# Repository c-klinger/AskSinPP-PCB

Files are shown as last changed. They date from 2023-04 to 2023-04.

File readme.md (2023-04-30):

# AskSin++ PSB
Collection of my PCBs for building Homebrew devices using [AskSin++](https://github.com/pa-pa/AskSinPP).

## HB-UNI-328P
soon...

## HB-UNI-328P-SMALL
Flexible and small (49x49mm) PCB for AskSin++ devices with multiple power options. Small enough to fit into devices that integrate into german wall socket / switch series.

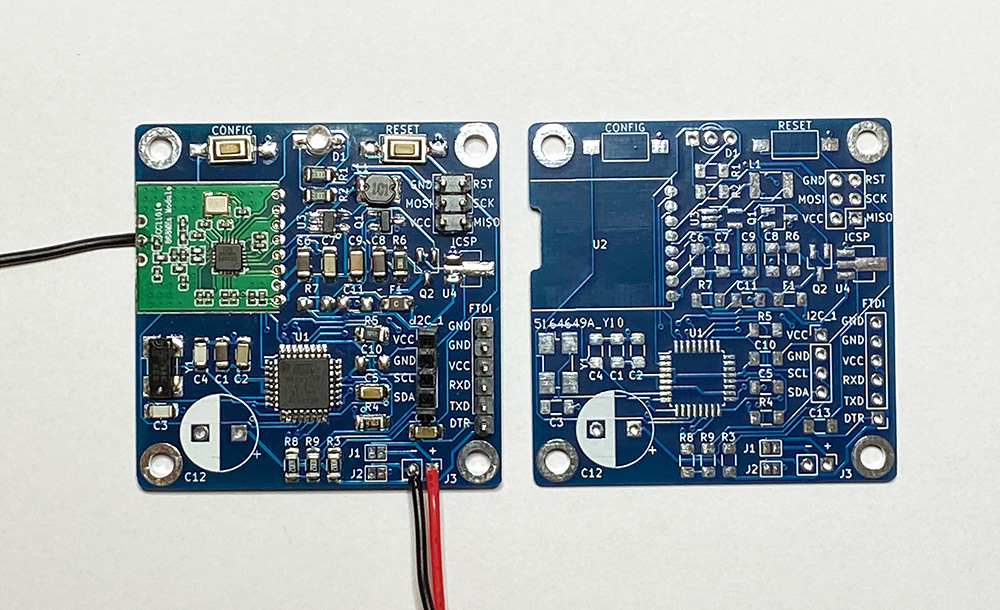
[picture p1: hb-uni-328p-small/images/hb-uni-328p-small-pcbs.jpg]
PCB Picture


[Schematics](https://github.com/c-klinger/AskSinPP-PCB/blob/main/hb-uni-328p-small/hb-uni-328p-small.pdf)

### Bill of Material

| Pos | References | Description | Value | Size | Quantity | Order Links \* | Notes |
|-----|---|---|---|---|---|---|---|
| 01 | U1 | ATmega328P(B) |  | TQFP-32 | 1 | [Reichelt](https://www.reichelt.de/8-bit-atmega-avr-mikrocontroller-32-kb-20-mhz-tqfp-32-atmega-328pb-au-p269093.html), [Aliexpress](https://s.click.aliexpress.com/e/_DmFgvzj) | |
| 02 | U2 | CC1101 Module |  |  | 1 | [Aliexpress](https://s.click.aliexpress.com/e/_DnFmipB) | |
| 03 | U3 | MAX1724EZK33 | | SOT-23 | 1 | [Mouser](https://www.mouser.de/ProductDetail/Analog-Devices-Maxim-Integrated/MAX1724EZK33%2bT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),  [Aliexpress](https://s.click.aliexpress.com/e/_DEjlEQt) | Only for Poweroption 1
| 04 | U4 | HT7533 | | SOT-89 | 1 | [ELV](https://de.elv.com/spannungsregler-33v-ht-7533-1-smd-sot-89-056535),  [Aliexpress](https://s.click.aliexpress.com/e/_Dkyk1p7)  | Only for Poweroption 2
| 05 | Q1 | IRLML6244 | | SOT-23 | 1 | [Reichelt](https://www.reichelt.de/mosfet-n-kanal-20-v-6-3-a-rds-on-0-021-ohm-sot-23-irlml-6244-p132145.html), [Aliexpress](https://s.click.aliexpress.com/e/_DmmdQxj) | only for Poweroption 1 
| 06 | Q2 | IRLML5203 | | SOT-23 | 1 | [Reichelt](https://www.reichelt.de/mosfet-p-kanal-30-v-3-a-rds-on-0-098-ohm-sot-23-irlml-5203-p108740.html), [Aliexpress](https://s.click.aliexpress.com/e/_DmmdQxj) | only for Poweroption 2 
| 07 | C1, C6, C8, C10, C11 | Capacitor | 10uF | 1206 | 4 (max) | [Reichelt](https://www.reichelt.de/ch/de/vielschicht-kerko-10-f-16v-125-c-kem-x7r1206-10u-p207163.html),  [Aliexpress](https://s.click.aliexpress.com/e/_DCrWg7b) | C8 for Poweroption 1, C10 + C11 for Poweroption 2
| 08 | C2, C7, C5 | Capacitor | 100nF | 1206 | 3 | [Reichelt](https://www.reichelt.de/smd-vielschicht-keramikkondensator-100n-10--x7r-g1206-100n-p22889.html),  [Aliexpress](https://s.click.aliexpress.com/e/_DCrWg7b) | |
| 09 | C3, C4 | Capacitor | 9-12pF | 1206 | 2 | [Reichelt](https://www.reichelt.de/vielschicht-kerko-1206-10-pf-5-cog-50-v-125-c-ve-4k-npo-g1206-10p-p31885.html), [Aliexpress](https://s.click.aliexpress.com/e/_DCrWg7b) | |
| 10 | C9  | Capacitor | 33nF | 1206 | 1 | [Reichelt](https://www.reichelt.de/smd-vielschicht-keramikkondensator-33n-10--x7r-g1206-33n-p22890.html), [Aliexpress](https://s.click.aliexpress.com/e/_DCrWg7b) | only for Poweroption 1 |
| 11 | C12  | Electrolytic Capacitor | 1000uF |  | 1 | [Reichelt](https://www.reichelt.de/elko-1000-f-50v-105-c-rad-lxz-50-1k0-p166432.html), [Aliexpress](https://s.click.aliexpress.com/e/_DCrWg7b) | only for Poweroption 2 |
| 12 | C13  | Capacitor | 10nF | 1206 | 1 | [Reichelt](https://www.reichelt.de/vielschicht-kerko-1206-10-nf-10-x7r-50-v-125-c-x7r-g1206-10n-p31897.html), [Aliexpress](https://s.click.aliexpress.com/e/_DCrWg7b) |  | 
| 13 | D1 | Dual LED | | 3mm | 1 | [Reichelt](https://www.reichelt.de/ch/de/led-3-mm-tht-3-pin-rot-gruen-627-565-nm-40-40-mcd-60--kbt-l-115wegw-p231039.html), [Aliexpress](https://s.click.aliexpress.com/e/_DFd0iCd) |  |
| 14 | F1 | Fuse (PTC) | 6V, 250mA | 1206 | 1 | [Aliexpress](https://s.click.aliexpress.com/e/_DEQvumh) | for Poweroption 1 |
| | F1 | Fuse (PTC) | 16V, 250mA | 1206 | 1 | [Reichelt](https://www.reichelt.de/ptc-sicherung-smd-1206-16v-350ma-rueckstellend-ptc-fsmd0351206--p279338.html), [Aliexpress](https://s.click.aliexpress.com/e/_DEQvumh) | for Poweroption 2 |
| 15 | J3 | Pin Header 2.54mm |  | 2x1 | 1 | [Reichelt](https://www.reichelt.de/ch/de/stiftleisten-2-54-mm-1x02-gerade-mpe-087-1-002-p119879.html), [Aliexpress](https://s.click.aliexpress.com/e/_Dl2TPCt) | optional |
| 16 | J4 | Pin Header 2.54mm |  | 6x1 | 1 | [Reichelt](https://www.reichelt.de/ch/de/stiftleisten-2-54-mm-1x06-gerade-mpe-087-1-006-p119883.html), [Aliexpress](https://s.click.aliexpress.com/e/_Dl2TPCt) | optional |
| 17 | J5 | Pin Header 2.54mm |  | 3x2 | 1 | [Reichelt](https://www.reichelt.de/ch/de/stiftleisten-2-54-mm-2x03-gerade-mpe-087-2-006-p119893.html), [Aliexpress](https://s.click.aliexpress.com/e/_DFoS9I5) | optional |
| 18 | J6 | Pin Header 2.54mm |  | 4x1 | 1 | [Reichelt](https://www.reichelt.de/ch/de/stiftleisten-2-54-mm-1x04-gerade-mpe-087-1-004-p119881.html), [Aliexpress](https://s.click.aliexpress.com/e/_Dl2TPCt) | optional|
| 19 | L1 | Induction Coil | 10UH | 4x3mm| 1| [Conrad](https://www.conrad.de/de/p/murata-lqh43cn100k03l-lqh43cn100k03l-induktivitaet-smd-1812-10-h-0-65-a-1-st-537082.html) [Aliexpress](https://s.click.aliexpress.com/e/_DFXlwZn) |only for Poweroption 1 |
| 10 | R1, R2 | Resistor | 330 | 1206 | 2 | [Richelt](https://www.reichelt.de/ch/de/smd-widerstand-1206-330-ohm-250-mw-1--vis-crcw1206330-p238114.html), [Aliexpress](https://s.click.aliexpress.com/e/_DDa77BX) |  |
| 21 | R3, R8, R9 | Resistor | 10K | 1206 | 3 | [Reichelt](https://www.reichelt.de/ch/de/smd-widerstand-1206-10-kohm-250-mw-5--smd-1-4w-10k-p18244.html) [Aliexpress](https://s.click.aliexpress.com/e/_DDa77BX) |  |
| 22 | R4 | Resistor | 470K | 1206 | 1 | [Reichelt](https://www.reichelt.de/ch/de/smd-widerstand-1206-470-kohm-250-mw-5--smd-1-4w-470k-p18338.html), [Aliexpress](https://s.click.aliexpress.com/e/_DDa77BX) |  |
| 23 | R5, R6, R7 | Resistor | 100K | 1206 | 3 (max) | [Reichelt](https://www.reichelt.de/ch/de/smd-widerstand-1206-100-kohm-250-mw-5--smd-1-4w-100k-p18243.html), [Aliexpress](https://s.click.aliexpress.com/e/_DDa77BX) | R7 for Poweroption 2 only |
| 24 | SW1, SW2 | Tactile Switch | | 6x3mm | 2 | [Aliexpress](https://s.click.aliexpress.com/e/_DlZyH0Z) | |
| 25 | Y1 |  SMD Crystal | 32.768 KHz | 3.8x8mm | 1 | [Reichelt](https://www.reichelt.de/ch/de/keramik-smd-quarz-8-7-x-3-7-x-2-5-mm-32-768-khz-iqd-lfxtal003000-p245481.html), [Aliexpress](https://s.click.aliexpress.com/e/_Dn3q3Az) | |

\* *I have not tested all parts using this order links, no guarantee that every linked component works. Aliexpress links are affiliate links, so i will get a small commission when you order using this link. This will help me with further projects. Thanks.*

### Comments
* Minimum size of SMD components is 1206: it's possible to solder the PCB by hand.
* 3 Power Options
    * Poweroption 1: Step-Up DC-DC Converter MAX1724EZK33: 0.8V to 5.5V Input Voltage Range. Best for Battery powered devices.
    * Poweroption 2: Linear Voltage Regulators (LDO) HT7533: 5-12V Input Voltage Range. Best for most external DC Power Supply. Jumper J2 needs to be shortened for this Poweroption. 
    * Poweroption 3: External 3.3V Supply. Jumper J1 and J2 needs to be shortened this Poweroption. No fuse or reverse polarity protection!
* Assembly and use only one of the Power Options at time.

Inspired from pa-pa [HMSensor](https://github.com/pa-pa/HMSensor) and [HB-UNI-644](https://github.com/alexreinert/PCB#hb-uni-644-rev-2) from alexreinert. Thanks for your work.

# LICENSE


All content in this repository is is licensed under a [Creative Commons Attribution-NonCommercial-ShareAlike 4.0 International license](https://creativecommons.org/licenses/by-nc-sa/4.0/).

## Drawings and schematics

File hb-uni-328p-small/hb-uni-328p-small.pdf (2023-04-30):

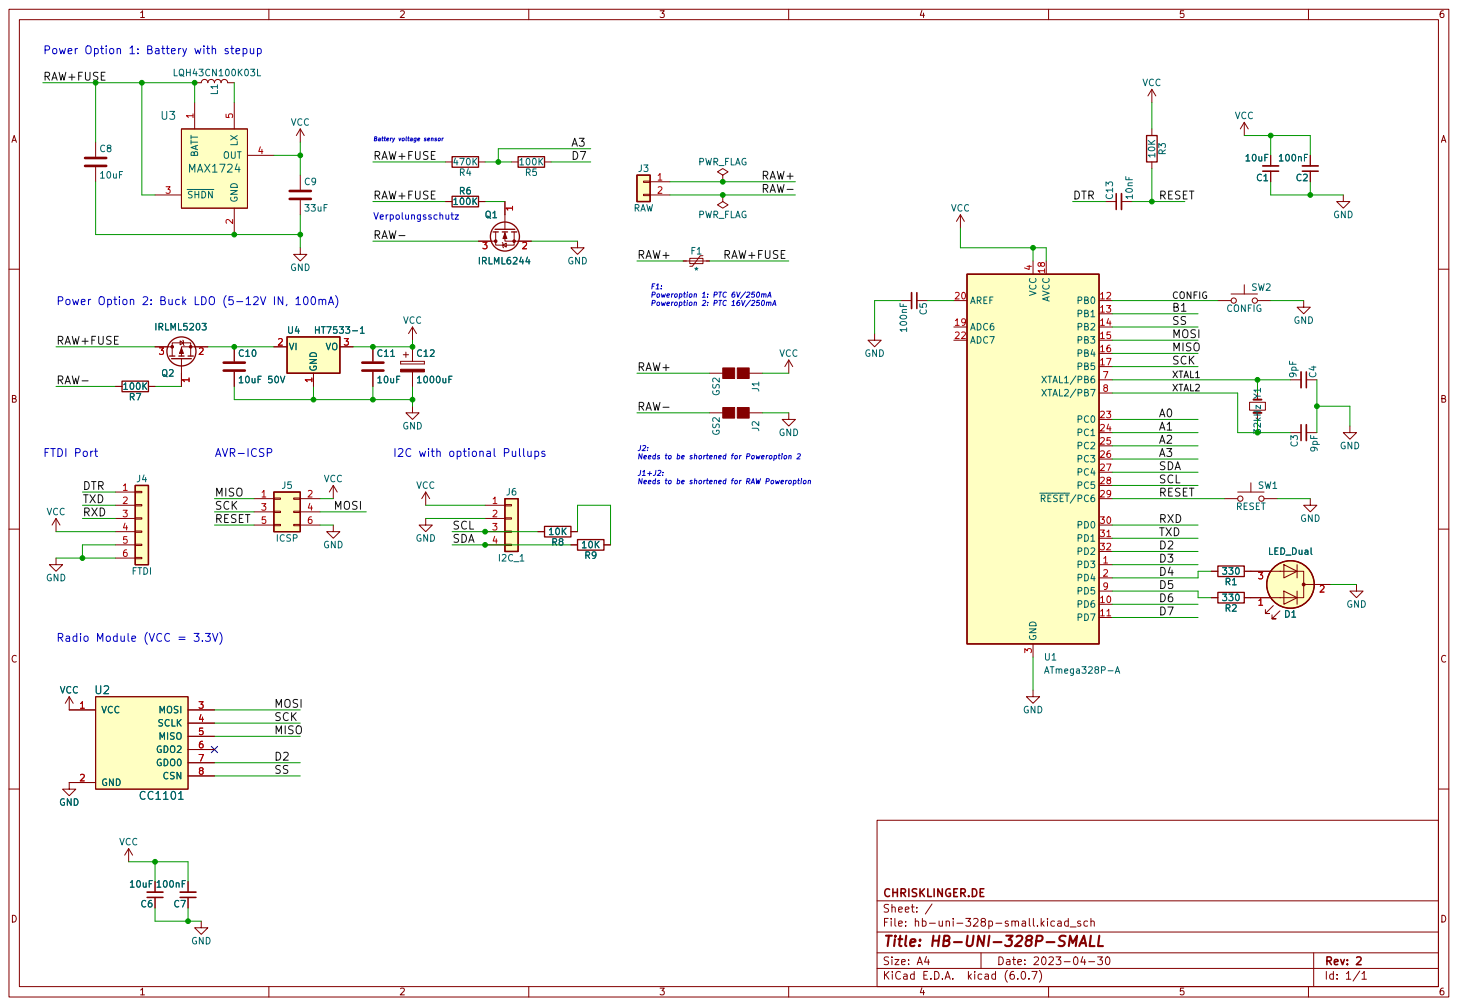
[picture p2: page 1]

2 ~{SHDN} 3 OUT 4 LX U3 5 MAX1724 GND

MOSI CONFIG D6 RAW+FUSE

J1+J2: Needs to be shortened for RAW Poweroption F1: Poweroption 1: PTC 6V/250mA

XTAL2 SCL RAW- RAW+FUSE

J2: Needs to be shortened for Poweroption 2

File: hb-uni-328p-small.kicad_sch Sheet: / CHRISKLINGER.DE

Id: 1/1 Title: HB-UNI-328P-SMALL

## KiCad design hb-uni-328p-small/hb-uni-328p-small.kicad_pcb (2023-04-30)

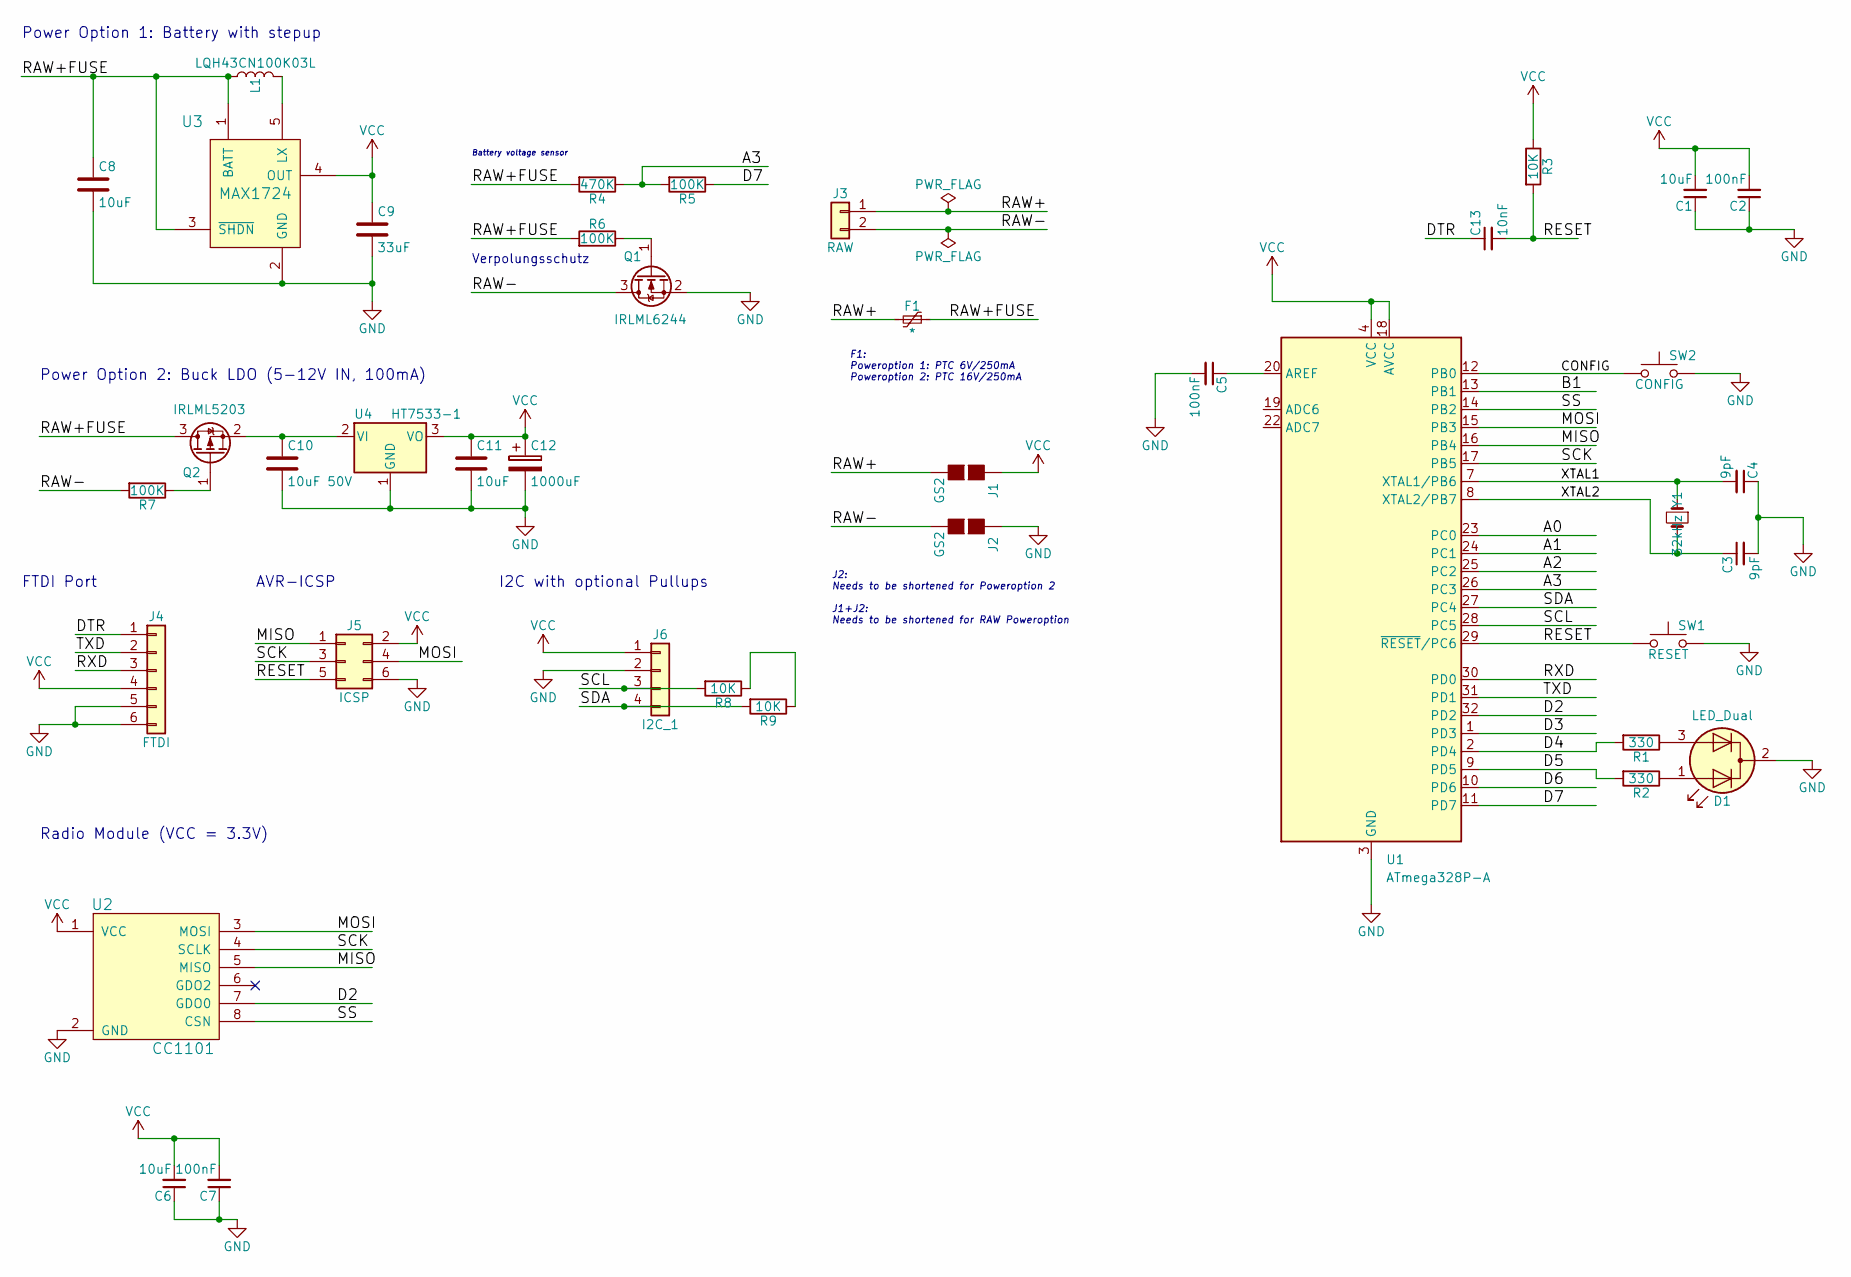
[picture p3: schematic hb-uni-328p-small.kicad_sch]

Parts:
C1, C6, C8, C11: 10uF; C_1206_3216Metric_Pad1.33x1.80mm_HandSolder
C2, C5, C7: 100nF; C_1206_3216Metric_Pad1.33x1.80mm_HandSolder
C3, C4: 9pF; C_1206_3216Metric_Pad1.33x1.80mm_HandSolder
C9: 33uF; C_1206_3216Metric_Pad1.33x1.80mm_HandSolder
C10: 10uF 50V; C_1206_3216Metric_Pad1.33x1.80mm_HandSolder
C12: 1000uF; CP_Radial_D10.0mm_P5.00mm
C13: 10nF; C_1206_3216Metric_Pad1.33x1.80mm_HandSolder
D1: LED_Dual; LED_D3.0mm-3
F1: *; R_1206_3216Metric_Pad1.30x1.75mm_HandSolder
J1, J2: GS2; SolderJumper-2_P1.3mm_Open_Pad1.0x1.5mm
J3: RAW; PinHeader_1x02_P2.54mm_Vertical
J4: FTDI; PinHeader_1x06_P2.54mm_Vertical
J5: ICSP; PinHeader_2x03_P2.54mm_Vertical
J6: I2C_1; PinHeader_1x04_P2.54mm_Vertical
L1: LQH43CN100K03L; L_1812_4532Metric_Pad1.30x3.40mm_HandSolder
Q1: IRLML6244; SOT-23_Handsoldering
Q2: IRLML5203; SOT-23_Handsoldering
R1, R2: 330; R_1206_3216Metric_Pad1.30x1.75mm_HandSolder
R3, R8, R9: 10K; R_1206_3216Metric_Pad1.30x1.75mm_HandSolder
R4: 470K; R_1206_3216Metric_Pad1.30x1.75mm_HandSolder
R5, R6, R7: 100K; R_1206_3216Metric_Pad1.30x1.75mm_HandSolder
SW1: RESET; SW_SPST_FSMSM
SW2: CONFIG; SW_SPST_FSMSM
U1: ATmega328P-A; TQFP-32_7x7mm_P0.8mm
U2: CC1101; CC1101-868MHz-Module
U3: MAX1724; TSOT-23-5_HandSoldering
U4: HT7533-1; SOT-89-3_Handsoldering
Y1: 32kHz; Crystal_SMD_0603-4Pin_6.0x3.5mm_HandSoldering

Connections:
/A0: U1.23 (PC0)
/A1: U1.24 (PC1)
/A2: U1.25 (PC2)
/A3: R4.1, R5.2, U1.26 (PC3)
/B1: U1.13 (PB1)
/CONFIG: SW2.1, U1.12 (PB0)
/D2: U1.32 (PD2), U2.7 (GDO0)
/D3: U1.1 (PD3)
/D4: R1.2, U1.2 (PD4)
/D5: R2.2, U1.9 (PD5)
/D6: U1.10 (PD6)
/D7: R5.1, U1.11 (PD7)
/DTR: C13.1, J4.1
/MISO: J5.1, U1.16 (PB4), U2.5 (MISO)
/MOSI: J5.4, U1.15 (PB3), U2.3 (MOSI)
/RAW+: F1.2, J1.2 (G2), J3.1
/RAW+FUSE: C8.1, F1.1, L1.1, Q2.3 (D), R4.2, R6.2, U3.1 (BATT), U3.3 (~SHDN)
/RAW-: J2.2 (G2), J3.2, Q1.3 (D), R7.2
/RESET: C13.2, J5.5, R3.2, SW1.1, U1.29 (~RESET/PC6)
/RXD: J4.3, U1.30 (PD0)
/SCK: J5.3, U1.17 (PB5), U2.4 (SCLK)
/SCL: J6.3, R8.2, U1.28 (PC5)
/SDA: J6.4, R9.2, U1.27 (PC4)
/SS: U1.14 (PB2), U2.8 (CSN)
/TXD: J4.2, U1.31 (PD1)
/XTAL1: C4.2, U1.7 (XTAL1/PB6), Y1.1
/XTAL2: C3.1, U1.8 (XTAL2/PB7), Y1.4
GND: C1.1, C2.1, C3.2, C4.1, C5.2, C6.1, C7.1, C8.2, C9.2, C10.2, C11.2, C12.2, D1.2 (K), J2.1 (G1), J4.5, J4.6, J5.6, J6.2, Q1.2 (S), SW1.2, SW2.2, U1.3 (GND), U1.5 (GND), U1.21 (GND), U2.2 (GND), U3.2 (GND), U4.1 (GND)
unnamed: C5.1, U1.20 (AREF)
unnamed: C10.1, Q2.2 (S), U4.2 (VI)
unnamed: D1.1 (A1), R2.1
unnamed: D1.3 (A2), R1.1
unnamed: L1.2, U3.5 (LX)
unnamed: Q1.1 (G), R6.1
unnamed: Q2.1 (G), R7.1
unnamed: R8.1, R9.1
VCC: C1.2, C2.2, C6.2, C7.2, C9.1, C11.1, C12.1, J1.1 (G1), J4.4, J5.2, J6.1, R3.1, U1.4 (VCC), U1.6 (VCC), U1.18 (AVCC), U2.1 (VCC), U3.4 (OUT), U4.3 (VO)

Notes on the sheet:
Radio Module (VCC = 3.3V)
AVR-ICSP
Battery voltage sensor
Verpolungsschutz
FTDI Port
Power Option 1: Battery with stepup
Power Option 2: Buck LDO (5-12V IN, 100mA)
J2: Needs to be shortened for Poweroption 2 J1+J2: Needs to be shortened for RAW Poweroption
I2C with optional Pullups
F1: Poweroption 1: PTC 6V/250mA Poweroption 2: PTC 16V/250mA

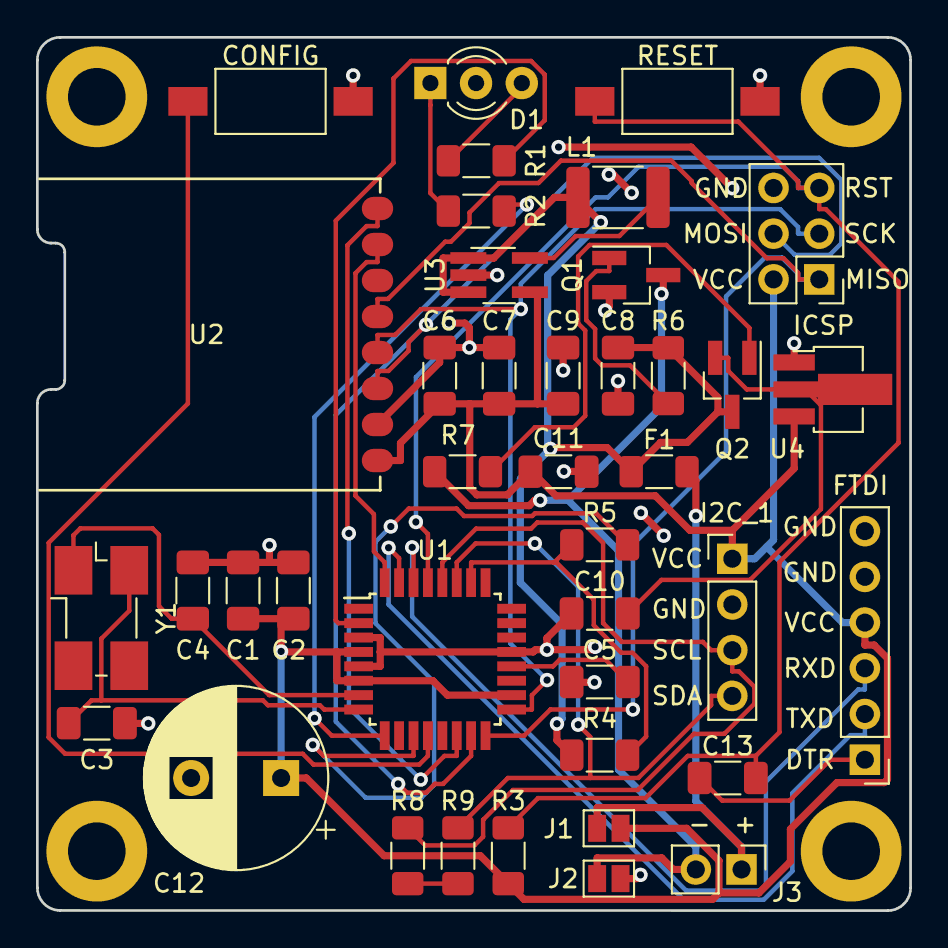
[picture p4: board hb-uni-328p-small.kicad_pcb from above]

Board: 2 copper layers, 48.5 x 48.5 mm, 44 parts (0 on the bottom side), 31 nets.

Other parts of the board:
REF2, REF4, REF6, REF7: MountingHole_3.2mm_M3_DIN965_Pad

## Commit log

2023-04-30 Initial commit, HB-UNI-328P-SMALL
    [hb-uni-328p-small-B_Cu.gbr, hb-uni-328p-small-B_Mask.gbr, hb-uni-328p-small-B_Paste.gbr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]
2023-04-30 fixed schematics link in readme

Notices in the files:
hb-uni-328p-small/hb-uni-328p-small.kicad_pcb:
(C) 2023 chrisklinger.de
